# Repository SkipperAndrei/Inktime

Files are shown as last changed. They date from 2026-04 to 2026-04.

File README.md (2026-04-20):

# InkTime Watch

Made by: Giurgiu Andrei-Ștefan 335CA

## Cuprins

1. [Prezentare generală](#1-prezentare-generală)
2. [Diagramă bloc](#2-diagramă-bloc)
3. [BOM – Bill of Materials](#3-bom--bill-of-materials)
4. [Descrierea hardware în detaliu](#4-descrierea-hardware-în-detaliu)
5. [Pinout nRF52840 – atribuire completă](#5-pinout-nrf52840--atribuire-completă)
6. [Estimare consum de energie](#6-estimare-consum-de-energie)
7. [Arhitectura firmware](#7-arhitectura-firmware)
8. [Aplicația mobilă companion](#8-aplicația-mobilă-companion)
9. [Randări produs](#9-randări-produs)

---

## 1. Prezentare generală

**InkTime** este un smartwatch conceput pentru a oferi:

- Afișaj e-paper 1.54" (200×200 px) cu refresh parțial o dată pe minut pentru un cadran digital clar, lizibil la orice lumină.
- Notificări BLE de pe telefon (profil tipic: ≤ 50 notificări/zi) cu alerte haptic.
- Numărare pași permanentă prin accelerometru cu pedometru integrat și trezire prin întrerupere.
- Încărcare USB-C și cale robustă de recuperare/programare prin Tag-Connect TC2030 SWD.

**Principii de proiectare:**

| Principiu | Descriere |
|---|---|
| Power first | Consum mediu minimizat; design interrupt-driven; fără conexiune BLE permanentă |
| Glanceable | UI simplu, contrast ridicat, fără ecrane dense cu text |
| Deterministic | Stări de putere predictibile; cale de recuperare robustă; fără stări hardware nedefinite |
| Buildable | Asamblare SMT repetabilă (JLC) și pași de asamblare manuală expliciți |

---

## 2. Diagramă bloc
Schema bloc

**Legendă interfețe:**

| Interfață | Componente conectate |
|---|---|
| I²C (shared bus) | BQ25180, RT6160, MAX17048, BMA421, DRV2605L |
| SPI | E-paper display controller |
| GPIO | Butoane, PFET e-paper, întreruperi (INT1/INT2 accel, ALRT fuel gauge, /INT charger) |
| USB | nRF52840 native USB (D+/D-) + VBUS detect |
| SWD | Tag-Connect TC2030 (SWDIO, SWDCLK, nRESET) |

---

## 3. BOM – Bill of Materials

| # | Funcție | Componentă | Pachet | LCSC Part | Link JLCPCB | Datasheet |
|---|---|---|---|---|---|---|
| 1 | MCU (BLE + USB) | nRF52840-QIAA-R | aQFN73 7×7 | C190794 | [JLCPCB](https://jlcpcb.com/partdetail/NordicSemiconductor-nRF52840QIAAR/C190794) | [Datasheet](https://infocenter.nordicsemi.com/pdf/nRF52840_PS_v1.7.pdf) |
| 2 | Charger / power-path | BQ25180YBGR | DSBGA-8 | C3682423 | [JLCPCB](https://jlcpcb.com/partdetail/TexasInstruments-BQ25180YBGR/C3682423) | [Datasheet](https://www.ti.com/lit/ds/symlink/bq25180.pdf) |
| 3 | Regulator 3.3V buck-boost | RT6160AWSC | WLCSP-15 | C7065276 | [JLCPCB](https://jlcpcb.com/partdetail/RichtekTech-RT6160AWSC/C7065276) | [Datasheet](https://www.richtek.com/assets/product_file/RT6160A/DS6160A-01.pdf) |
| 4 | Fuel gauge | MAX17048G+T10 | DFN-8 2×2 | C2682616 | [JLCPCB](https://jlcpcb.com/partdetail/MaximIntegrated-MAX17048GT10/C2682616) | [Datasheet](https://www.analog.com/media/en/technical-documentation/data-sheets/MAX17048-MAX17049.pdf) |
| 5 | Accelerometru / pedometru | BMA421 | LGA-12 2×2 | C5242966 | [JLCPCB](https://jlcpcb.com/partdetail/BoschSensortec-BMA421/C5242966) | [Datasheet](https://www.bosch-sensortec.com/media/boschsensortec/downloads/datasheets/bst-bma421-ds000.pdf) |
| 6 | Driver haptic | DRV2605LDGSR | VSSOP-10 | C527464 | [JLCPCB](https://jlcpcb.com/partdetail/TexasInstruments-DRV2605LDGSR/C527464) | [Datasheet](https://www.ti.com/lit/ds/symlink/drv2605l.pdf) |
| 7 | Motor vibrant ERM | LCM1027B3605F | Wire leads | C7528806 | [JLCPCB](https://jlcpcb.com/partdetail/C7528806) | [Datasheet](https://datasheet.lcsc.com/lcsc/2208251630_NOVASEN-LCM1027B3605F_C7528806.pdf) |
| 8 | PFET (power gate EPD) | SI2301CDS | SOT-23 | C10487 | [JLCPCB](https://jlcpcb.com/partdetail/Vishay-SI2301CDS/C10487) | [Datasheet](https://www.vishay.com/docs/63524/si2301cds.pdf) |
| 9 | Conector debug | Tag-Connect TC2030-IDC | PCB footprint | — | [Tag-Connect](https://www.tag-connect.com/product/tc2030-idc-nl) | [Pinout](https://www.tag-connect.com/wp-content/uploads/bsk-pdf-manager/2019/10/TC2030-IDC-NL.pdf) |
| 10 | Afișaj e-paper | 1.54" EPD 200×200 (Good Display GDEW0154M09 sau echivalent) | FPC | — | [Good Display](https://www.good-display.com) | [Datasheet](https://www.good-display.com/companyfile/459.html) |

---

## 4. Descrierea hardware în detaliu

### 4.1 MCU – nRF52840-QIAA

nRF52840 este microcontrolerul central al proiectului. Integrează:

- Procesor ARM Cortex-M4F @ 64 MHz
- Radio BLE 5.0 + IEEE 802.15.4
- USB 2.0 Full Speed nativ (D+/D-)
- 1 MB Flash, 256 KB RAM
- Periferice hardware: multiple SPI, I²C, UART, PWM, ADC, comparatoare

**Alimentare MCU:**

| Rail | Conexiune | Valoare / Notă |
|---|---|---|
| VDD (toți pinii) | VDD 3V3 | 3.3V de la RT6160 |
| VDDH | VDD 3V3 | Mod normal-voltage (nu high-voltage) |
| VSS + pad expus | GND plane | |
| DEC1 | 100nF la GND | |
| DEC4 + DEC6 | 1µF la GND | Nodul DC/DC intern REG1 |
| DECUSB | 4.7µF la GND | Filtrare USB |

**DC/DC intern (REG1):** Firmware-ul activează DCDC1 la runtime. Circuitul extern: DCC → 10µH → 15nH → nod DEC4/DEC6.

**Cristale:**

| Cristal | Pini | Scopul |
|---|---|---|
| 32 MHz | XC1 / XC2 | Sistem principal, radio BLE, USB |
| 32.768 kHz | XL1 / XL2 | RTC, timekeeping, minute tick |

Condensatorii de sarcină ai cristalelor se dimensionează în funcție de CL-ul cristalului ales (ajustare posibilă pe board).

---

### 4.2 Charger – BQ25180YBGR

BQ25180 este un charger linear/power-path pentru LiPo de până la 1A, cu interfață I²C.

**Rol în sistem:**

- Primește 5V de pe USB-C pe pinul IN.
- Oferă VSYS pe pinul SYS — rail intermediar care alimentează regulatorul RT6160.
- Gestionează încărcarea bateriei LiPo pe pinul BAT cu protecție integrată (supraîncărcare, supraîncălzire, scurtcircuit).

**Conexiuni cheie:**

| Pin BQ25180 | Conexiune |
|---|---|
| IN | VBUS 5V (USB) |
| BAT | VBAT (LiPo +) |
| SYS | VSYS → RT6160 VIN |
| SCL / SDA | I²C shared bus |
| /INT | GPIO MCU (întrerupere opțională pentru evenimente charger) |
| TS / MR | Strapped cu 10kΩ la GND (Rev A) |

**Decuplare:** CIN = 1µF, CSYS = 10µF, CBAT = 1µF (minim, dimensionate cu derating termic).

**Adresă I²C:** `0x6A`

---

### 4.3 Regulator 3.3V – RT6160AWSC

RT6160 este un convertor buck-boost care menține 3.3V fix pe toată plaja de descărcare a LiPo (de la ~4.2V până la ~3.0V și sub). Asigură că VBAT scăzut nu provoacă brownout pe MCU sau periferice.

**Conexiuni cheie:**

| Pin RT6160 | Conexiune |
|---|---|
| VIN | VSYS (ieșirea SYS a BQ25180) |
| VOUT | VDD 3V3 |
| VSEL | GND (selectează fix 3.3V) |
| EN | VSYS (always-on când VSYS e prezent) |
| SCL / SDA | I²C shared bus (opțional, pentru telemetrie / DVFS viitor) |

**Componentă externă putere:** Inductor 0.47µH, input multi-22µF, output 10µF (valori recomandate Richtek).

**Adresă I²C:** `0x75`

---

### 4.4 Fuel Gauge – MAX17048G+T10

MAX17048 măsoară tensiunea bateriei LiPo prin algoritmul ModelGauge și raportează SOC (State of Charge) în procente prin I²C.

**Conexiuni cheie:**

| Pin MAX17048 | Conexiune |
|---|---|
| BAT / VDD | VBAT |
| SDA / SCL | I²C shared bus |
| ALRT | GPIO MCU (active low, pull-up la VDD 3V3) → sursă de trezire din sleep |

**Decuplare:** 0.1µF lângă VDD.

**Adresă I²C:** `0x36`

**Funcționalitate:** Pinul ALRT generează o întrerupere când SOC scade sub pragul configurat (ex. 5%) — MCU se trezește, afișează avertisment baterie slabă și/sau inițiază BLE disconnect.

---

### 4.5 Accelerometru / Pedometru – BMA421

BMA421 este un accelerometru triaxial de înaltă performanță cu pedometru hardware integrat, optimizat pentru purtabila (consum < 200µA în mod step counter).

**Mod de operare principal:** I²C (CSB strapped high, SDO strapped low → adresă 0x18).

**Conexiuni cheie:**

| Pin BMA421 | Conexiune |
|---|---|
| VDD / VDDIO | VDD 3V3 (decuplare 0.1µF per pin) |
| SDA / SCL | I²C shared bus |
| CSB | High → mod I²C |
| SDO | Low → adresă 0x18 |
| INT1 | P0.08 → trezire primară din Deep Sleep (pas detectat, motion) |
| INT2 | P1.08 → evenimente secundare / debug |

**Funcționalitate:** Pedometrul hardware numără pași fără implicarea MCU-ului. MCU se trezește doar la întreruperea INT1 pentru a citi și cumula datele, reducând consumul la minimum.

---

### 4.6 Driver haptic – DRV2605L + Motor ERM LCM1027B3605F

DRV2605L controlează motorul vibrant ERM (Eccentric Rotating Mass) prin forme de undă preprogramate stocate în ROM intern (biblioteca Immersion HD), selectate prin I²C.

**Conexiuni cheie:**

| Pin DRV2605L | Conexiune |
|---|---|
| VDD | VDD 3V3 (decuplare locală) |
| SDA / SCL | I²C shared bus |
| EN | P0.12 → shutdown complet între evenimente haptic |
| OUT+ / OUT- | Terminalele motorului ERM |

**Adresă I²C:** `0x5A`

**Politică de consum:** EN pus LOW între evenimente haptic elimină curentul de quiescent al driverului. Motorul rulează doar pe durata unui pattern (tipic 50–300ms).

---

### 4.7 Afișaj E-paper 1.54" (200×200)

Afișajul e-paper păstrează imaginea fără consum de energie în stare statică — ideal pentru un cadran de ceas. Consumă curent doar în timpul refresh-ului.

**Interfață:** SPI + 3 GPIO de control.

**Conexiuni cheie:**

| Semnal | Pin MCU | Rol |
|---|---|---|
| SCK | P0.02 | Clock SPI |
| MOSI | P0.03 | Date SPI (write-only) |
| CS | P0.05 | Chip select |
| DC | P0.15 | Data / Command select |
| RST | P0.16 | Reset panel |
| BUSY | P0.17 | Semnal panel ocupat (polling) |
| PFET gate | P1.01 | Power gate VEPD (prin rezistor 100Ω; pull-up 100kΩ gate-source) |

**Power gating VEPD:** Un P-FET (SI2301CDS) comutează alimentarea afișajului (VEPD) din VDD 3V3. Firmware-ul poate dezactiva VEPD complet între refresh-uri pentru a elimina curentul de leakage al display-ului și al FPC.

**Politică refresh:**

- Refresh parțial la fiecare minut (time update) — consum minim, fără ghosting vizibil pe termen scurt.
- Refresh complet la intervale configurabile (ex. la fiecare oră sau la cerere) pentru eliminarea ghosting-ului acumulat.

**Rezistori de serie opționali (DNP):** 100Ω–1kΩ pe liniile SPI/control pentru a reduce riscul de back-power când VEPD este dezactivat.

---

### 4.8 Butoane

Trei butoane mecanice active-low:

| Buton | Pin MCU | Conexiune |
|---|---|---|
| UP | P0.13 | GPIO → Switch → GND |
| DOWN | P0.14 | GPIO → Switch → GND |
| ENTER / ESC | P1.00 | GPIO → Switch → GND |

Firmware-ul activează pull-up intern pe fiecare pin și configurează wake-on-low + debounce software (tipic 20–50ms).

---

### 4.9 Interfața de programare – Tag-Connect TC2030 SWD

| Pin TC2030 | Semnal |
|---|---|
| 1 | VTref (VDD 3V3) — referință tensiune pentru debugger |
| 2 | SWDIO |
| 3 | GND |
| 4 | SWDCLK |
| 5 | GND |
| 6 | nRESET |

Board-ul este self-powered (baterie sau USB); TC2030 nu trebuie să furnizeze curent. VTref este obligatoriu pentru ca debugger-ul să detecteze tensiunea I/O a target-ului.

---

## 5. Pinout nRF52840 – atribuire completă

| Pin nRF52840 | Funcție | Componentă / Semnal | Justificare alegere |
|---|---|---|---|
| P0.02 | SPI SCK | E-paper clock | SPI0 hardware; alocare convenabilă pentru routing PCB |
| P0.03 | SPI MOSI | E-paper date | SPI0 hardware |
| P0.05 | SPI CS | E-paper chip select | GPIO flexibil, contiguitate cu celelalte pini SPI |
| P0.06 | I²C SDA | Bus I²C shared | I2C0 hardware Nordic; pull-up extern 10kΩ |
| P0.07 | I²C SCL | Bus I²C shared | I2C0 hardware Nordic; pull-up extern 10kΩ |
| P0.08 | GPIO INPUT | BMA421 INT1 | Capacitate sense GPIO → wake din Deep Sleep; pin cu DETECT |
| P0.12 | GPIO OUTPUT | DRV2605L EN | Control shutdown haptic; GPIO simplu sufficient |
| P0.13 | GPIO INPUT | Buton UP | Sense GPIO, wake-on-low, pull-up intern |
| P0.14 | GPIO INPUT | Buton DOWN | Sense GPIO, wake-on-low, pull-up intern |
| P0.15 | GPIO OUTPUT | EPD DC | Control Data/Command display; GPIO rapid |
| P0.16 | GPIO OUTPUT | EPD RST | Reset panel; GPIO simplu |
| P0.17 | GPIO INPUT | EPD BUSY | Polling stare panel; GPIO simplu |
| P1.00 | GPIO INPUT | Buton ENTER/ESC | Sense GPIO, wake-on-low, pull-up intern |
| P1.01 | GPIO OUTPUT | PFET gate VEPD | Control alimentare afișaj; pull-up extern gate-source (default OFF) |
| P1.08 | GPIO INPUT | BMA421 INT2 | Eveniment secundar accelerometru / debug |
| USBDP / USBDM | USB D+ / D- | USB-C conector | Pereche diferențială native USB nRF52840; ESD lângă conector |
| VBUS | USB VBUS detect | USB 5V | Detecție attach/detach USB |
| SWDIO / SWDCLK | SWD | TC2030 pin 2 / 4 | Programare și debug hardware |
| nRESET | Reset | TC2030 pin 6 | Resetare externă prin debugger |
| XC1 / XC2 | Crystal 32 MHz | Cristal extern | Ceas sistem, radio BLE, USB |
| XL1 / XL2 | Crystal 32.768 kHz | Cristal RTC extern | RTC, minute tick, sleep scheduling |
| DEC1 | Decuplare | 100nF → GND | Rail intern nRF |
| DEC4 / DEC6 | Decuplare DC/DC | 1µF → GND | Nod inductor DC/DC REG1 |
| DECUSB | Decuplare USB | 4.7µF → GND | Filtrare rail USB intern |

**Bus I²C – hartă adrese (7-bit):**

| Adresă | Dispozitiv |
|---|---|
| 0x18 | BMA421 (accelerometru) |
| 0x36 | MAX17048 (fuel gauge) |
| 0x5A | DRV2605L (haptic driver) |
| 0x6A | BQ25180 (charger) |
| 0x75 | RT6160 (regulator) |

---

## 6. Estimare consum de energie

### 6.1 Profilul tipic de utilizare

| Eveniment | Frecvență | Energie estimată |
|---|---|---|
| Refresh parțial e-paper | 1×/minut | ~5–15 mJ/refresh |
| Notificare BLE + haptic + display | 50×/zi | ~10–20 mJ/eveniment |
| Step counter (BMA421) | continuu (MCU dormit) | ~5–10 µA curent static BMA421 |
| Deep Sleep MCU | majoritar | ~3–5 µA (MCU) + RTC |

### 6.2 Buget curent mediu (estimat)

| Componentă | Curent mediu estimat |
|---|---|
| nRF52840 Deep Sleep + RTC | ~3 µA |
| BMA421 step counter mode | ~5 µA |
| MAX17048 activ | ~23 µA |
| E-paper (static, VEPD off) | ~0 µA |
| E-paper refresh (parțial, 1/min, pulsed) | ~150–300 µA mediat pe minut |
| **Total estimat mediu** | **~180–340 µA** |

---

## 7. Arhitectura firmware

### 7.1 Stack

- **RTOS:** Zephyr OS (recomandat pentru maturitate BLE stack) sau event loop lightweight.
- **Limbaj:** C / C++ (Zephyr NCS).

### 7.2 Module principale

| Modul | Responsabilități |
|---|---|
| HAL | GPIO, I²C, SPI, timere, întreruperi, watchdog |
| Power Manager | Stări sleep, surse wake, duty cycles, power gating display |
| Timekeeping | RTC, timezone, sincronizare timp, planificare minute tick |
| Display Driver | Init, refresh parțial/complet, frame buffer, polling BUSY |
| BLE Manager | Advertising, conexiune, servicii GATT, notificări, bonding |
| Notification Service | Coadă mesaje, deduplicare, politică render, trigger haptic |
| Activity Service | Init BMA421, citire pași, reset zilnic |
| Battery Service | Citiri MAX17048, alerte baterie slabă, stare charger BQ25180 |
| Haptics Service | Init DRV2605L, pattern-uri, politică enable/disable |
| Storage | NVM pentru setări, istoric pași, preferințe notificări |
| Diagnostics | Log-uri debug, info build, hook-uri self-test |

### 7.3 Stări de putere și surse de trezire

```
┌─────────────┐   RTC tick / Button / INT / BLE event  ┌──────────────┐
│  Deep Sleep  │──────────────────────────────────────►│   Active      │
│ (radio off)  │◄──────────────────────────────────────│ (render/BLE)  │
└─────────────┘           Task complet                 └──────────────┘
        ▲                                                      │
        │                   Idle/Standby                       │
        └──────────────────────────────────────────────────────┘
```

**Surse de trezire din Deep Sleep:**

- RTC minute tick
- Butoane (GPIO sense)
- BMA421 INT1/INT2 (pași/mișcare)
- MAX17048 ALRT (prag baterie slabă)
- BQ25180 /INT (eveniment charger)
- BLE events (ferestre programate)

### 7.4 Servicii BLE GATT (MVP)

| Serviciu | UUID | Descriere |
|---|---|---|
| Device Information (DIS) | Standard | Model, versiune firmware |
| Battery Service (BAS) | Standard | Procent baterie (MAX17048) |
| Custom Notification Service | Custom | Push notificări, clear, ack |
| Time Sync | Custom | Setare oră/timezone; proxy NTP opțional |
| DFU Service | Custom (opțional) | Update firmware OTA |

**Payload notificare:** timestamp, app id, titlu, corp (trunchiat), prioritate, vibration pattern id — optimizat pentru BLE MTU cu suport chunking.

---

## 8. Aplicația mobilă companion

### 8.1 Strategie platformă

- MVP: o platformă prima (Android sau iOS), cu plan clar de paritate.
- Cross-platform: Flutter sau React Native dacă cerințele BLE stack sunt satisfăcute.
- Native: Kotlin (Android) / Swift (iOS) pentru fiabilitate BLE maximă.

### 8.2 Module app

| Modul | Responsabilități |
|---|---|
| BLE Transport | Scan, connect, bonding, MTU, reconectare, comportament background |
| Device Model | Stare cached: baterie, firmware, setări, last seen |
| Notification Bridge | Capturare notificări OS, filtrare, formatare, coadă send |
| Settings UI | Allowlist/blocklist, ore liniștite, pattern-uri vibrație |
| Time Service | Sincronizare oră + timezone, politică drift |
| DFU/Update | Download/verify firmware, transfer, progres, rollback |

### 8.3 Pipeline notificări

```
Eveniment OS → Filtrare reguli (app list, quiet hours) → Render payload compact →
→ Coadă cu retry/backoff (dacă watch deconectat) → Send BLE → Ack opțional
```

---

### 9 Randări produs

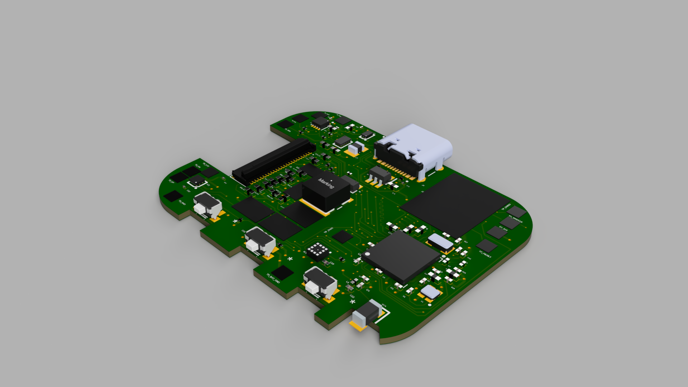
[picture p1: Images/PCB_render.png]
RandarePCB


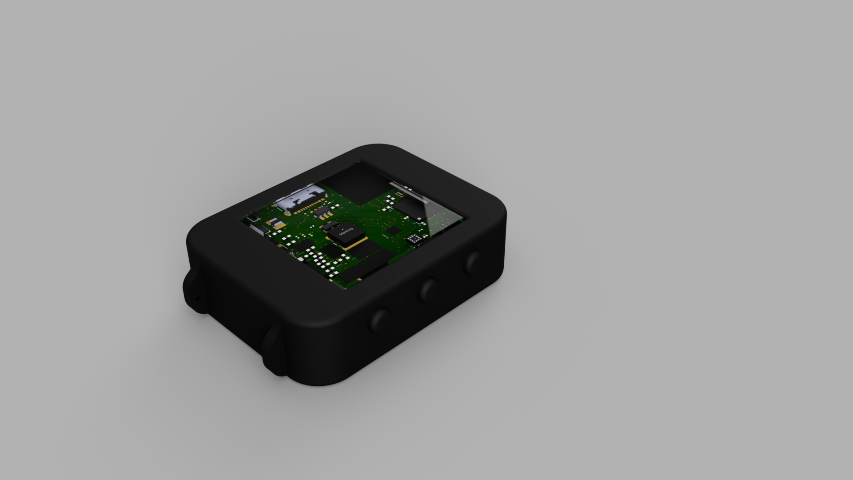
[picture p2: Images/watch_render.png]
RandareCeas


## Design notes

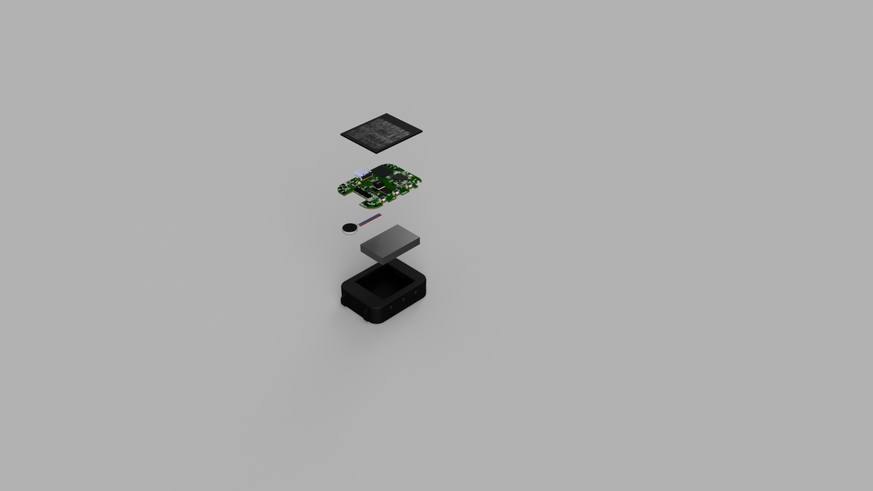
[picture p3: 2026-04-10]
Images/exploded_render.png

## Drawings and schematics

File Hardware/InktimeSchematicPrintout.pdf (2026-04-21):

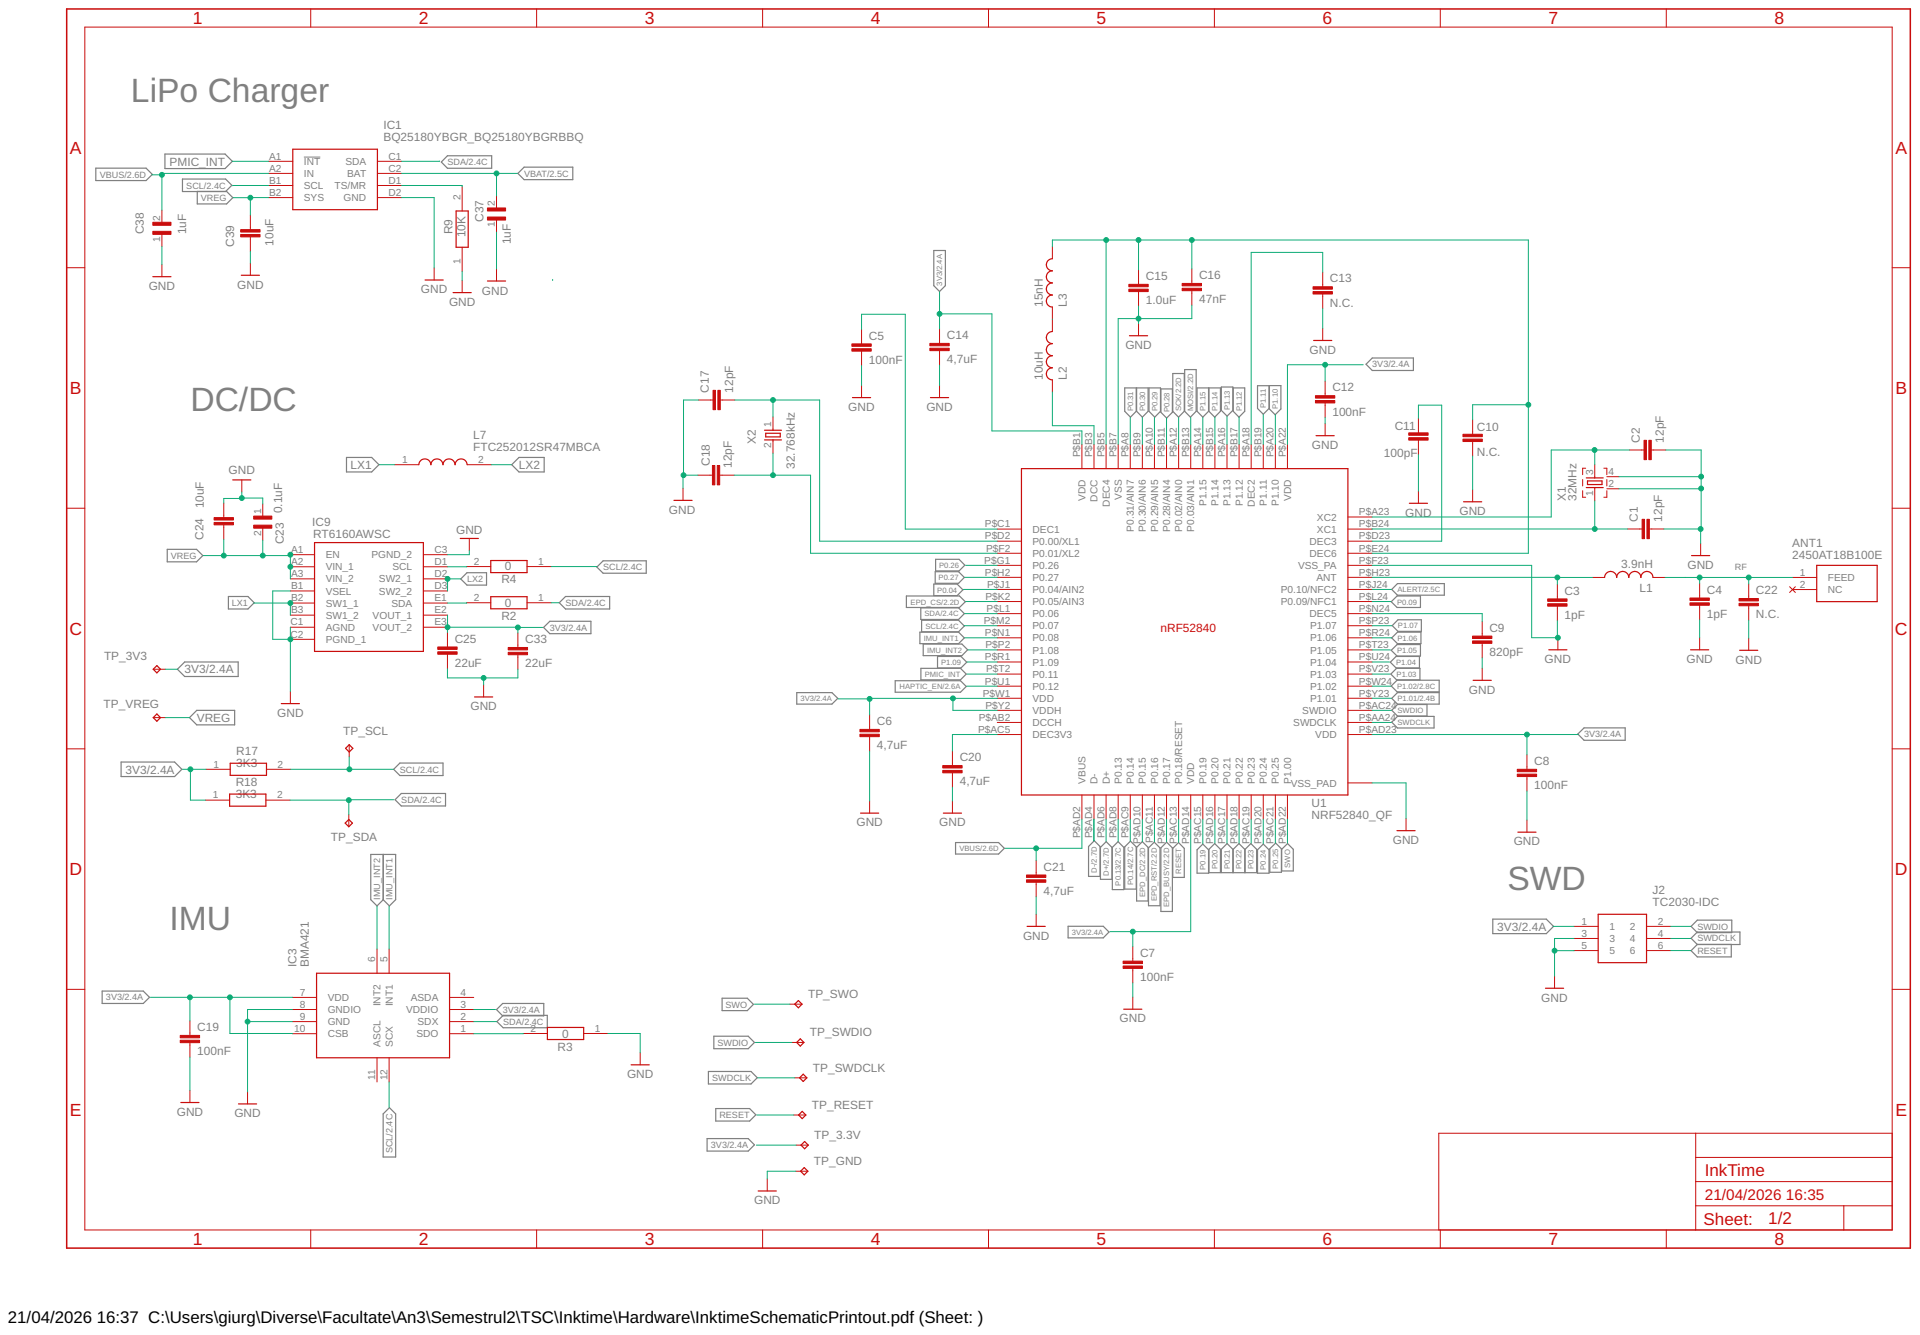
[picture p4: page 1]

21/04/2026 16:37 C:\Users\giurg\Diverse\Facultate\An3\Semestrul2\TSC\Inktime\Hardware\InktimeSchematicPrintout.pdf (Sheet: )

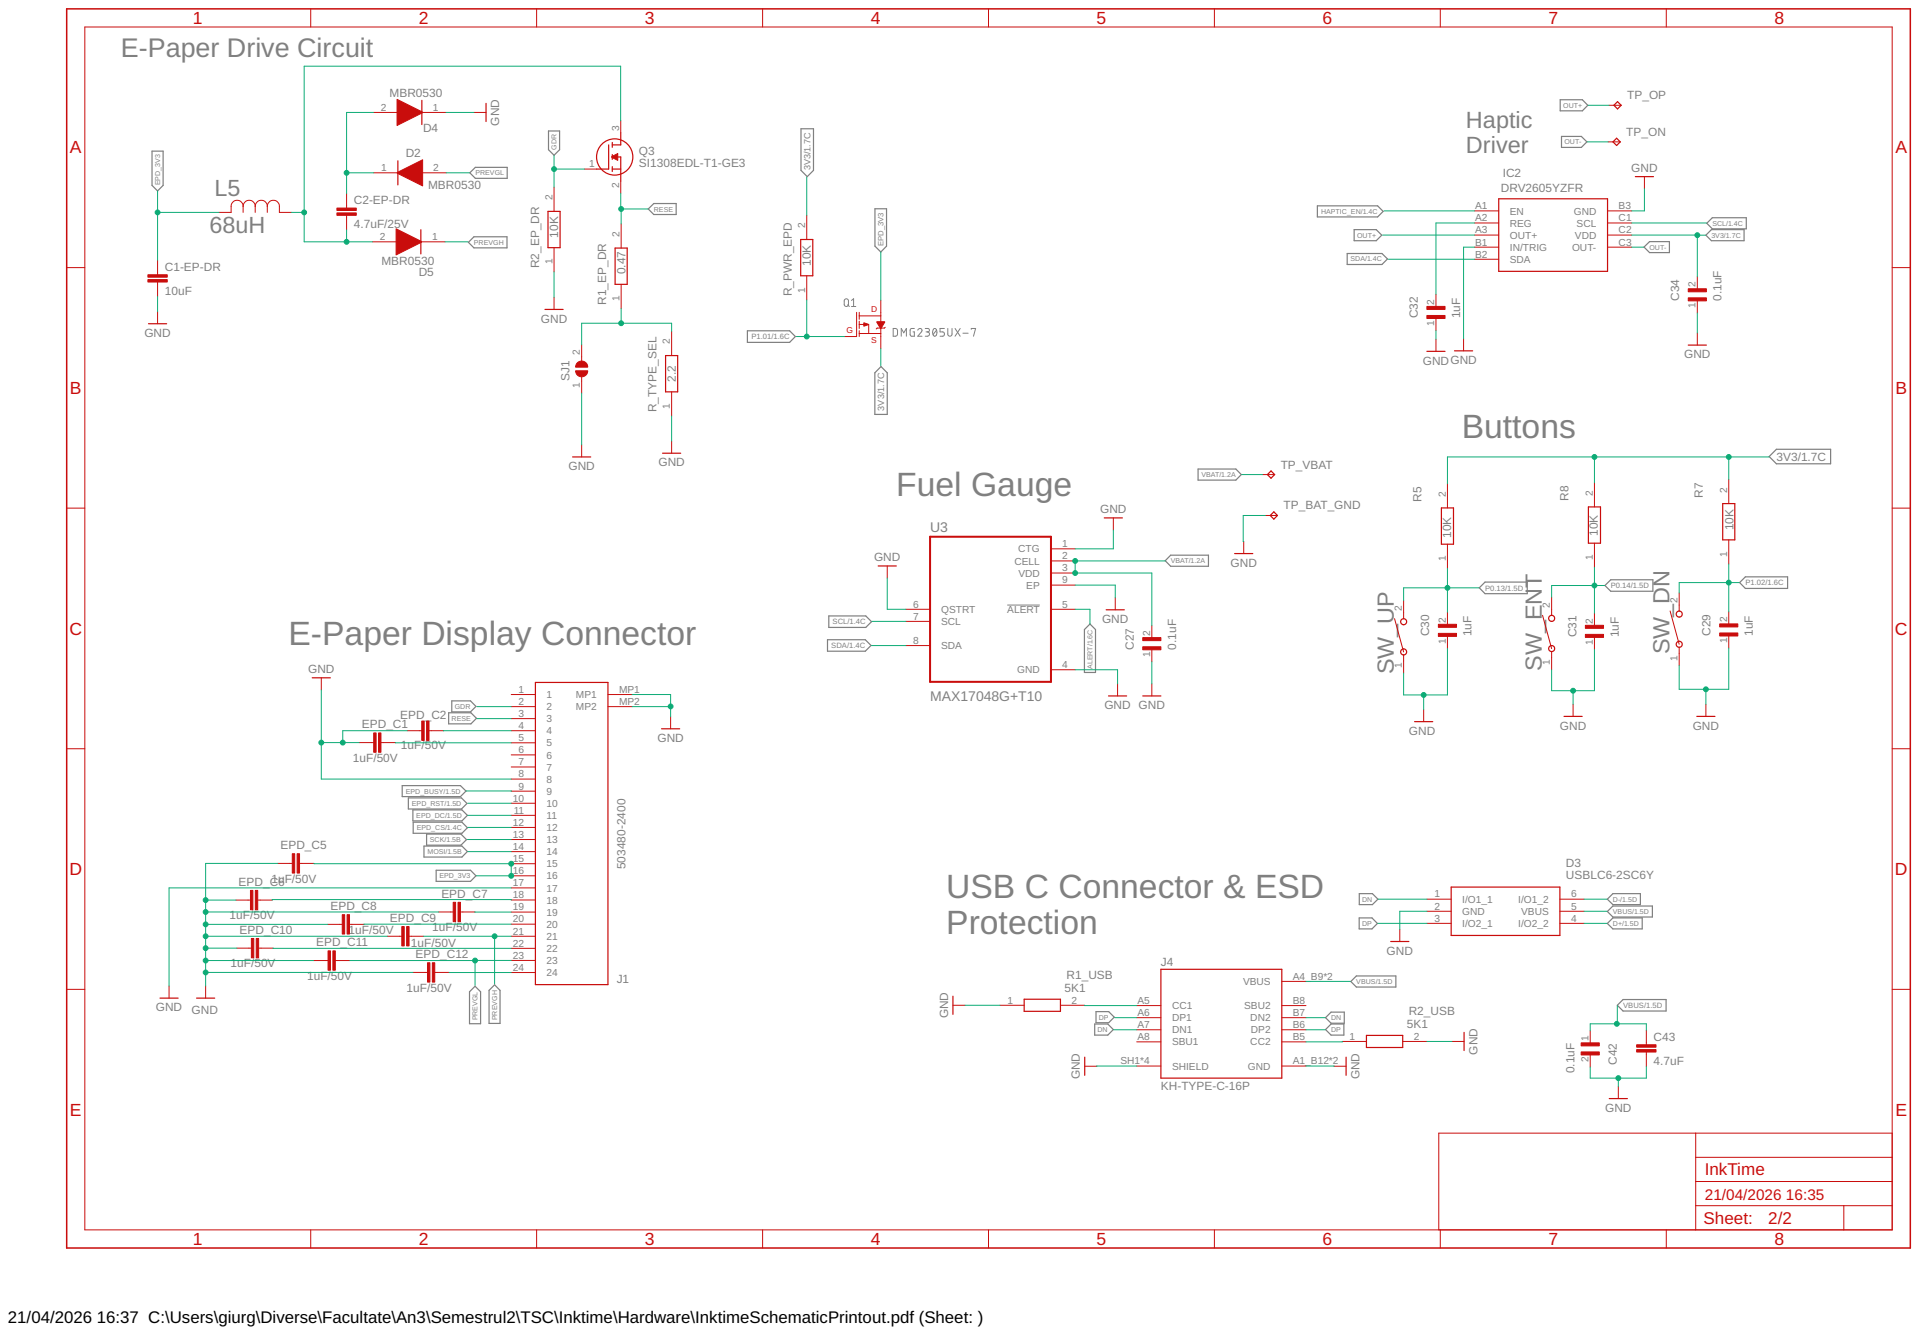
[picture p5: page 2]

EPD_C8 | 19

1uF/50V | EPD_C9 | 20
EPD_C10 | 1uF/50V | 1uF/50V 21

EPD_C11 | 1uF/50V | 22

EPD_C12 | 23

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

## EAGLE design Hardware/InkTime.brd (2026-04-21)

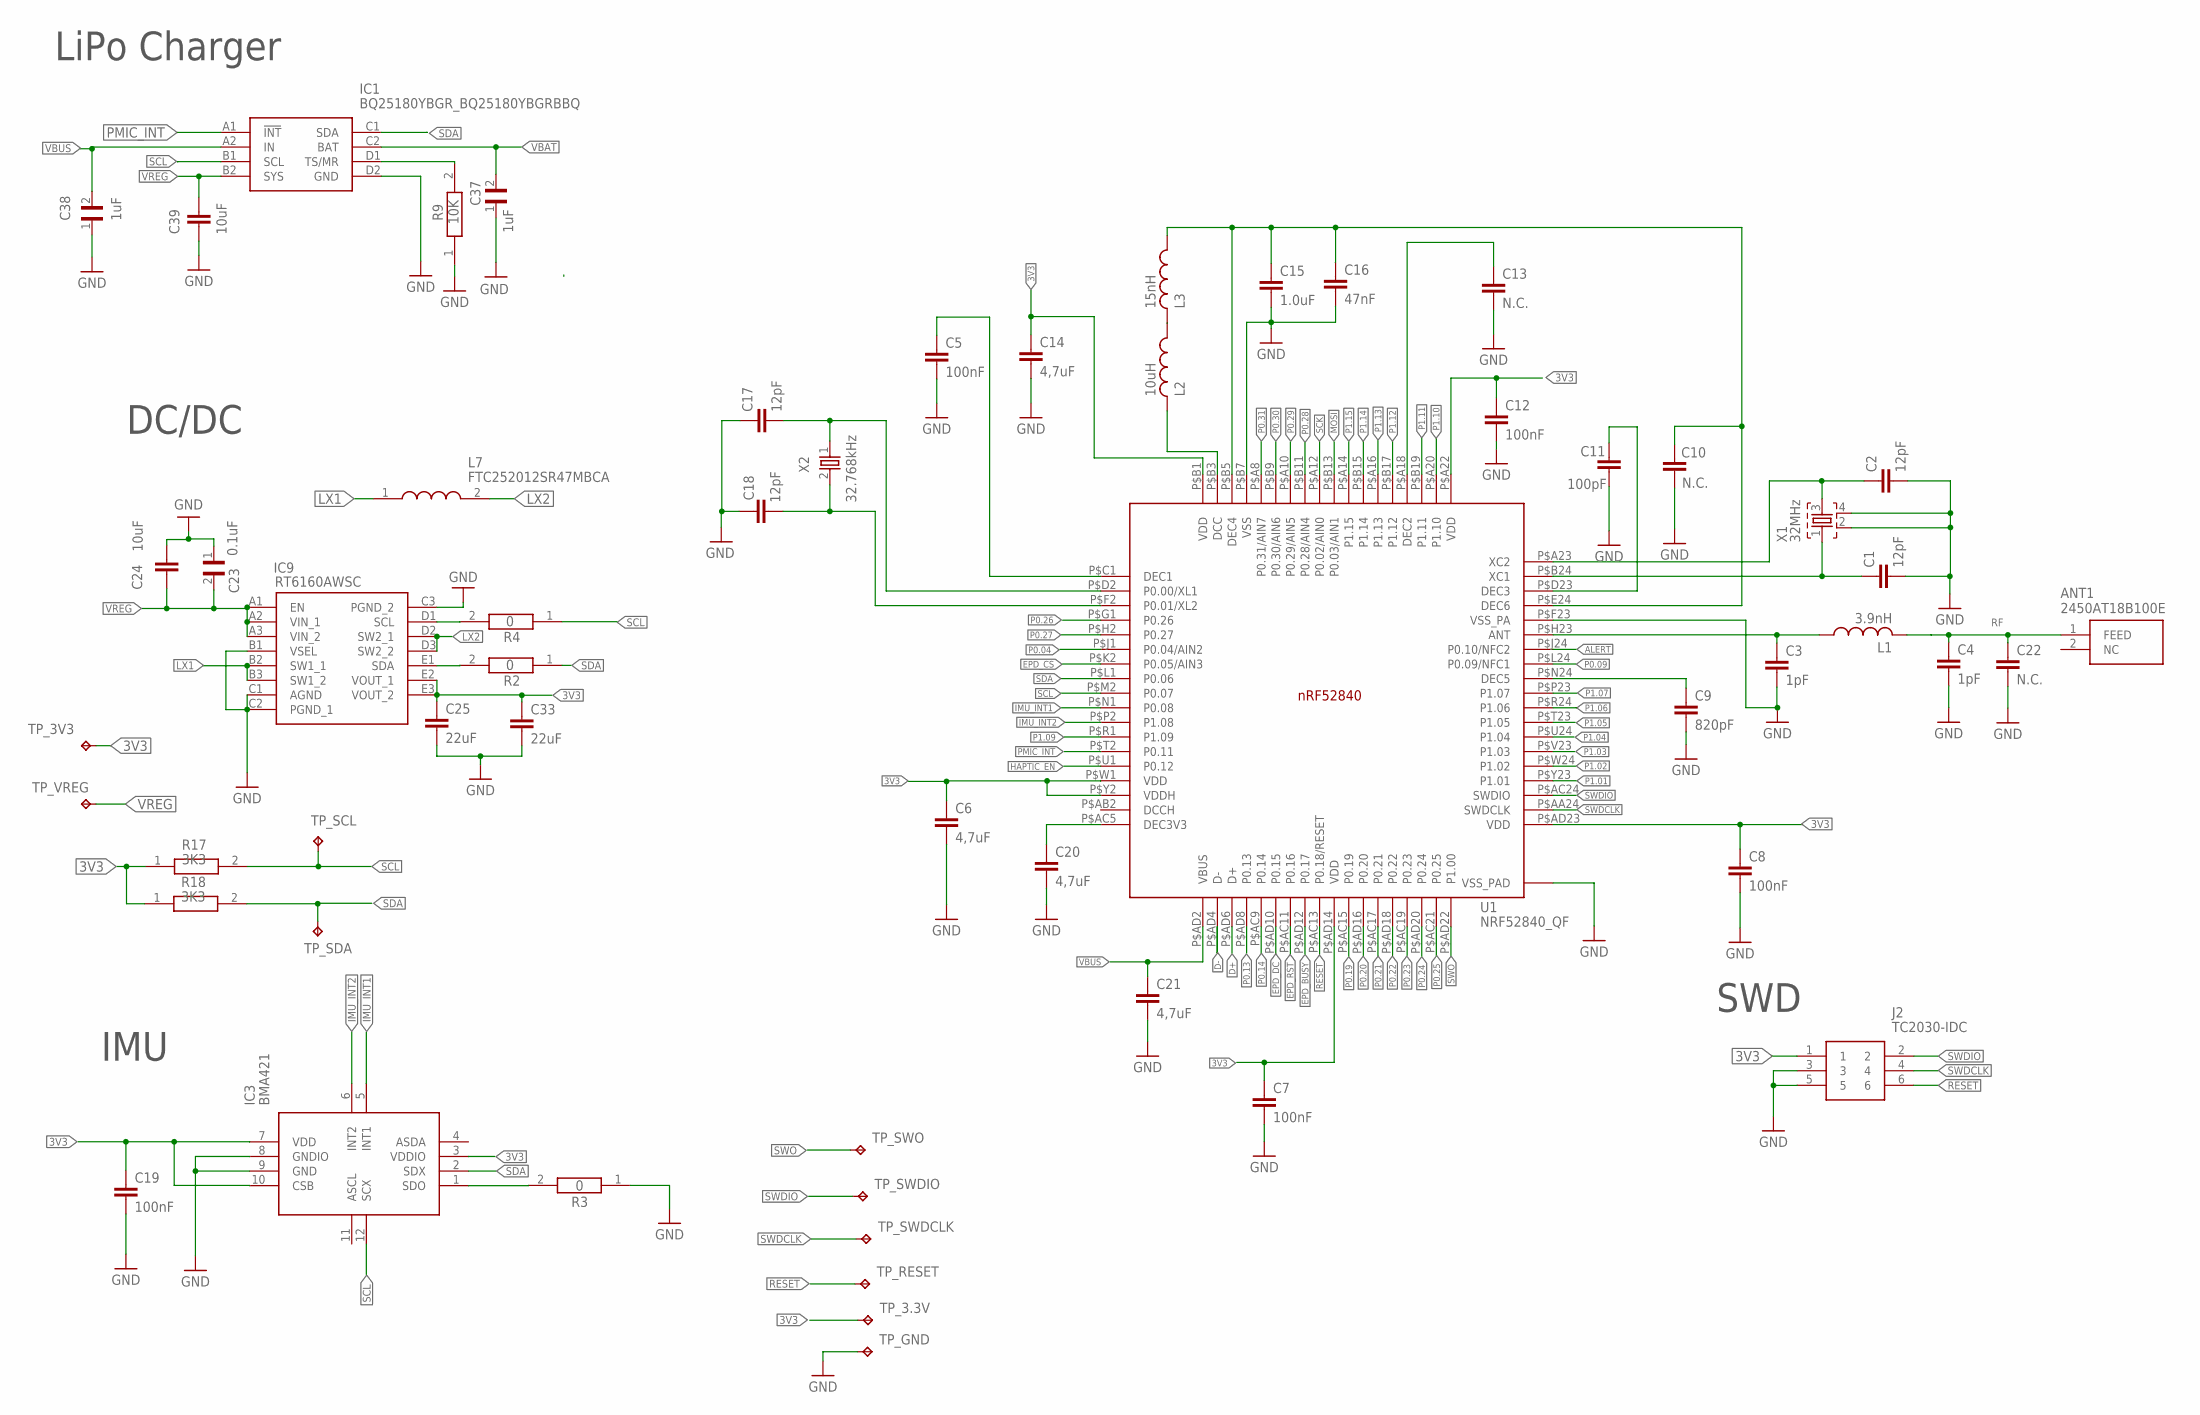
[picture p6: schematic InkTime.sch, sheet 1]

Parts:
ANT1: 2450AT18B100E; 2450AT18B100E_ANTC3216X140N
C1, C2, C17, C18: 12pF; NORDIC_NRF_3_RESC0201_N
C3, C4: 1pF; NORDIC_NRF_3_RESC0201_N
C5, C7, C8, C12, C19: 100nF; NORDIC_NRF_3_RESC0201_N
C6, C14, C20, C21: 4,7uF; NORDIC_NRF_3_RESC0402_N
C9: 820pF; NORDIC_NRF_3_RESC0201_N
C10, C13, C22: N.C.; NORDIC_NRF_3_RESC0201_N
C11: 100pF; NORDIC_NRF_3_RESC0201_N
C15: 1.0uF; NORDIC_NRF_3_RESC0402_N
C16: 47nF; NORDIC_NRF_3_RESC0201_N
C23: 0.1uF; GRM011R60J152KE01L_2_CAPC0201X13N
C24, C39: 10uF; NORDIC_NRF_3_RESC0402_N
C25, C33: 22uF; NORDIC_NRF_3_RESC0402_N
C37, C38: 1uF; GRM011R60J152KE01L_2_CAPC0201X13N
IC1: BQ25180YBGR_BQ25180YBGRBBQ; BQ25180YBGR_BGA8C40P2X4_100X155X50
IC3: BMA421; BMA423_BMA423
IC9: RT6160AWSC; RT6160AWSC_BGA15C40P3X5_140X230X60
J2: TC2030-IDC; TC2030-IDC_TC2030IDC
L1: 3.9nH; NORDIC_NRF_2_RESC0201_N
L2: 10uH; NORDIC_NRF_2_RESC0201_N
L3: 15nH; NORDIC_NRF_2_RESC0201_N
L7: FTC252012SR47MBCA; MLP2016SR47MT0S1_INDC2016X100N
R2, R3, R4: 0; CPF0201D7K68C1_0201
R9: 10K; CPF0201D7K68C1_0201
R17, R18: 3K3; CPF0201D7K68C1_0201
TP_3.3V, TP_3V3: HECTOR_WATCH_1_TPTP20R; HECTOR_WATCH_1_TP20R
TP_GND: HECTOR_WATCH_1_TPTP20R; HECTOR_WATCH_1_TP20R
TP_RESET: HECTOR_WATCH_1_TPTP20R; HECTOR_WATCH_1_TP20R
TP_SCL: HECTOR_WATCH_1_TPTP20R; HECTOR_WATCH_1_TP20R
TP_SDA: HECTOR_WATCH_1_TPTP20R; HECTOR_WATCH_1_TP20R
TP_SWDCLK: HECTOR_WATCH_1_TPTP20R; HECTOR_WATCH_1_TP20R
TP_SWDIO: HECTOR_WATCH_1_TPTP20R; HECTOR_WATCH_1_TP20R
TP_SWO: HECTOR_WATCH_1_TPTP20R; HECTOR_WATCH_1_TP20R
TP_VREG: HECTOR_WATCH_1_TPTP20R; HECTOR_WATCH_1_TP20R
U1: NRF52840_QF; NORDIC_NRF_4_AQFN50P700X700X85_HS-74N
X1: 32MHz; NORDIC_NRF_BT-XTAL_2016_N
X2: 32.768kHz; NORDIC_NRF_1_XTAL_3215_N

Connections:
3V3: C6.1, C7.1, C8.1, C12.1, C14.1, C19.1, C25.1, C33.1, IC3.3 (VDDIO), IC3.7 (VDD), IC3.10 (CSB), IC9.E2 (VOUT_1), IC9.E3 (VOUT_2), J2.1, R17.1, R18.1, TP_3.3V.TP, TP_3V3.TP, U1.P$A22 (VDD), U1.P$AD14 (VDD), U1.P$AD23 (VDD), U1.P$B1 (VDD), U1.P$W1 (VDD), U1.P$Y2 (VDDH); also elsewhere on the board
ALERT: U1.P$J24 (P0.10/NFC2); also elsewhere on the board
D+: U1.P$AD6 (D+); also elsewhere on the board
D-: U1.P$AD4 (D-); also elsewhere on the board
EPD_BUSY: U1.P$AD12 (P0.17); also elsewhere on the board
EPD_CS: U1.P$K2 (P0.05/AIN3); also elsewhere on the board
EPD_DC: U1.P$AD10 (P0.15); also elsewhere on the board
EPD_RST: U1.P$AC11 (P0.16); also elsewhere on the board
GND: C1.2, C2.2, C3.2, C4.2, C5.2, C6.2, C7.2, C8.2, C9.2, C10.2, C11.2, C12.2, C13.2, C14.2, C15.2, C16.2, C17.1, C18.2, C19.2, C20.2, C21.2, C22.2, C23.1, C24.1, C25.2, C33.2, C37.1, C38.1, C39.2, IC1.D2 (GND), IC3.8 (GNDIO), IC3.9 (GND), IC9.B1 (VSEL), IC9.C1 (AGND), IC9.C2 (PGND_1), IC9.C3 (PGND_2), J2.3, J2.5, R3.1, R9.1, TP_GND.TP, U1.P$74 (VSS_PAD), U1.P$75 (VSS_PAD), U1.P$76 (VSS_PAD), U1.P$77 (VSS_PAD), U1.P$78 (VSS_PAD), U1.P$79 (VSS_PAD), U1.P$80 (VSS_PAD), U1.P$81 (VSS_PAD), U1.P$82 (VSS_PAD), U1.P$83 (VSS_PAD), U1.P$84 (VSS_PAD), U1.P$85 (VSS_PAD), U1.P$86 (VSS_PAD), U1.P$87 (VSS_PAD), U1.P$88 (VSS_PAD), U1.P$89 (VSS_PAD), U1.P$90 (VSS_PAD), U1.P$B7 (VSS), U1.P$F23 (VSS_PA), X1.2, X1.4; also elsewhere on the board
HAPTIC_EN: U1.P$U1 (P0.12); also elsewhere on the board
IMU_INT1: IC3.5 (INT1), U1.P$N1 (P0.08)
IMU_INT2: IC3.6 (INT2), U1.P$P2 (P1.08)
LX1: IC9.B2 (SW1_1), IC9.B3 (SW1_2), L7.1
LX2: IC9.D2 (SW2_1), IC9.D3 (SW2_2), L7.2
MOSI: U1.P$B13 (P0.03/AIN1); also elsewhere on the board
unnamed: IC1.D1 (TS/MR), R9.2
unnamed: IC9.D1 (SCL), R4.2
unnamed: IC9.E1 (SDA), R2.2
unnamed: IC3.1 (SDO), R3.2
unnamed: C9.1, U1.P$N24 (DEC5)
unnamed: C3.1, L1.1, U1.P$H23 (ANT)
unnamed: C11.1, U1.P$D23 (DEC3)
unnamed: C10.1, C15.1, C16.1, L3.1, U1.P$B5 (DEC4), U1.P$E24 (DEC6)
unnamed: C2.1, U1.P$A23 (XC2), X1.3
unnamed: C1.1, U1.P$B24 (XC1), X1.1
unnamed: C13.1, U1.P$A18 (DEC2)
unnamed: L2.1, L3.2
unnamed: L2.2, U1.P$B3 (DCC)
unnamed: C5.1, U1.P$C1 (DEC1)
unnamed: C17.2, U1.P$D2 (P0.00/XL1), X2.1
unnamed: C18.1, U1.P$F2 (P0.01/XL2), X2.2
unnamed: C20.1, U1.P$AC5 (DEC3V3)
P0.04: U1.P$J1 (P0.04/AIN2)
P0.09: U1.P$L24 (P0.09/NFC1)
P0.13: U1.P$AD8 (P0.13); also elsewhere on the board
P0.14: U1.P$AC9 (P0.14); also elsewhere on the board
P0.19: U1.P$AC15 (P0.19)
P0.20: U1.P$AD16 (P0.20)
P0.21: U1.P$AC17 (P0.21)
P0.22: U1.P$AD18 (P0.22)
P0.23: U1.P$AC19 (P0.23)
P0.24: U1.P$AD20 (P0.24)
P0.25: U1.P$AC21 (P0.25)
P0.26: U1.P$G1 (P0.26)
P0.27: U1.P$H2 (P0.27)
P0.28: U1.P$B11 (P0.28/AIN4)
P0.29: U1.P$A10 (P0.29/AIN5)
P0.30: U1.P$B9 (P0.30/AIN6)
P0.31: U1.P$A8 (P0.31/AIN7)
P1.01: U1.P$Y23 (P1.01); also elsewhere on the board
P1.02: U1.P$W24 (P1.02); also elsewhere on the board
P1.03: U1.P$V23 (P1.03)
P1.04: U1.P$U24 (P1.04)
P1.05: U1.P$T23 (P1.05)
P1.06: U1.P$R24 (P1.06)
P1.07: U1.P$P23 (P1.07)
P1.09: U1.P$R1 (P1.09)
P1.10: U1.P$A20 (P1.10)
P1.11: U1.P$B19 (P1.11)
P1.12: U1.P$B17 (P1.12)
P1.13: U1.P$A16 (P1.13)
P1.14: U1.P$B15 (P1.14)
P1.15: U1.P$A14 (P1.15)
PMIC_INT: IC1.A1 (!INT), U1.P$T2 (P0.11)
RESET: J2.6, TP_RESET.TP, U1.P$AC13 (P0.18/RESET)
RF: ANT1.1 (FEED), C4.1, C22.1, L1.2
SCK: U1.P$A12 (P0.02/AIN0); also elsewhere on the board
SCL: IC1.B1 (SCL), IC3.12 (SCX), R4.1, R17.2, TP_SCL.TP, U1.P$M2 (P0.07); also elsewhere on the board
SDA: IC1.C1 (SDA), IC3.2 (SDX), R2.1, R18.2, TP_SDA.TP, U1.P$L1 (P0.06); also elsewhere on the board
SWDCLK: J2.4, TP_SWDCLK.TP, U1.P$AA24 (SWDCLK)
SWDIO: J2.2, TP_SWDIO.TP, U1.P$AC24 (SWDIO)
SWO: TP_SWO.TP, U1.P$AD22 (P1.00)
VBAT: C37.2, IC1.C2 (BAT); also elsewhere on the board
VBUS: C21.1, C38.2, IC1.A2 (IN), U1.P$AD2 (VBUS); also elsewhere on the board
VREG: C23.2, C24.2, C39.1, IC1.B2 (SYS), IC9.A1 (EN), IC9.A2 (VIN_1), IC9.A3 (VIN_2), TP_VREG.TP

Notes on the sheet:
LiPo Charger
DC/DC
IMU
SWD

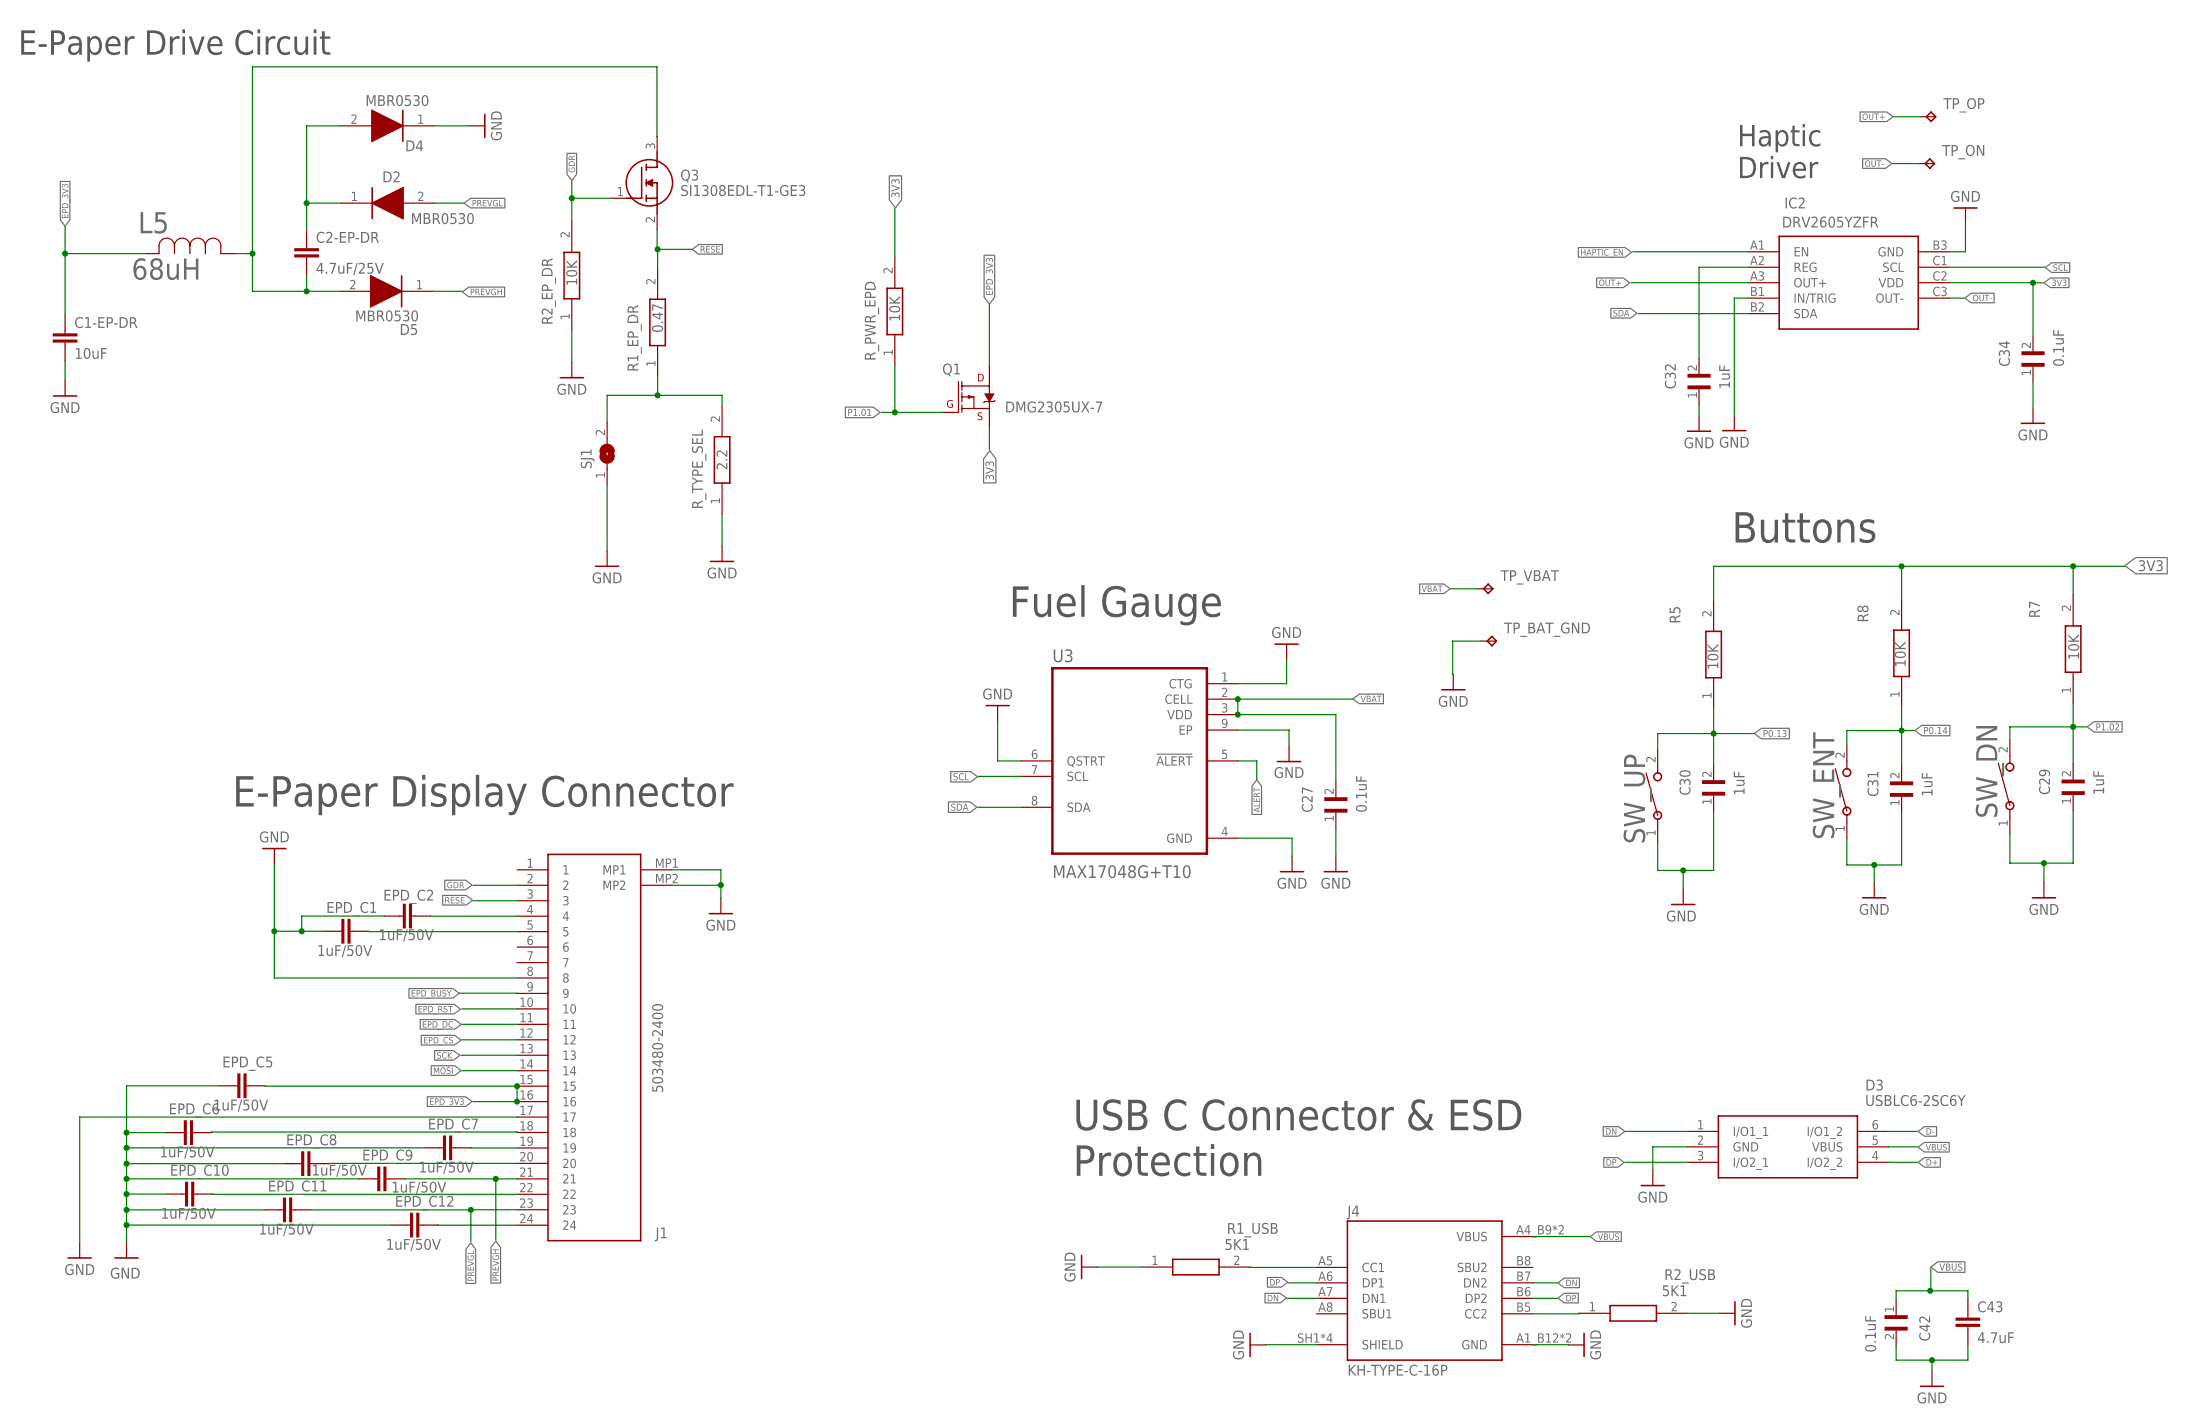
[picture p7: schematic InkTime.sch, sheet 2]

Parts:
C1-EP-DR: 10uF; NORDIC_NRF_3_RESC0402_N
C2-EP-DR: 4.7uF/25V; NORDIC_NRF_3_RESC0402_N
C27, C34, C42: 0.1uF; GRM011R60J152KE01L_2_CAPC0201X13N
C29, C30, C31, C32: 1uF; GRM011R60J152KE01L_2_CAPC0201X13N
C43: 4.7uF; NORDIC_NRF_3_RESC0402_N
D2, D4, D5: MBR0530; ESP32_C6_LIBRARY_5_SOD3716X135N
D3: USBLC6-2SC6Y; ESP32_C6_LIBRARY_3_SOT95P280X145-6N
EPD_C1, EPD_C2, EPD_C5, EPD_C6, EPD_C7, EPD_C8, EPD_C9, EPD_C10, EPD_C11, EPD_C12: 1uF/50V; NORDIC_NRF_3_RESC0402_N
IC2: DRV2605YZFR; DRV2605YZFR_BGA9C50P3X3_144X144X62
J1: 503480-2400; 503480-2400_5034802400
J4: KH-TYPE-C-16P; KH-TYPE-C-16P_KINGHELM_KH-TYPE-C-16P
L5: 68uH; ESP32_C6_LIBRARY_2_IND_4828-WE-TPC_WRE
Q1: DMG2305UX-7; ESP32_C6_LIBRARY_4_ESP32_C6_LIBRARY_4_ESP32_C6_LIBRARY_4_ES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
Q3: SI1308EDL-T1-GE3; ESP32_C6_LIBRARY_6_SOT65P210X110-3N
R1_EP_DR: 0.47; CPF0201D7K68C1_0201
R1_USB, R2_USB: 5K1; CPF0201D7K68C1_0201
R2_EP_DR, R5, R7, R8: 10K; CPF0201D7K68C1_0201
R_PWR_EPD: 10K; CPF0201D7K68C1_0201
R_TYPE_SEL: 2.2; CPF0201D7K68C1_0201
SJ1: ESP32_C6_LIBRARY_7_JUMPER_SJ
SW_DN: 2025-10-22_07-23-44_LIBRARY_EVP-AKE31A; 2025-10-22_07-23-44_LIBRARY_SW_EVP-AKE31A_PAN
SW_ENT: 2025-10-22_07-23-44_LIBRARY_EVP-AKE31A; 2025-10-22_07-23-44_LIBRARY_SW_EVP-AKE31A_PAN
SW_UP: 2025-10-22_07-23-44_LIBRARY_EVP-AKE31A; 2025-10-22_07-23-44_LIBRARY_SW_EVP-AKE31A_PAN
TP_BAT_GND: HECTOR_WATCH_1_TPTP20R; HECTOR_WATCH_1_TP20R
TP_ON: HECTOR_WATCH_1_TPTP20R; HECTOR_WATCH_1_TP20R
TP_OP: HECTOR_WATCH_1_TPTP20R; HECTOR_WATCH_1_TP20R
TP_VBAT: HECTOR_WATCH_1_TPTP20R; HECTOR_WATCH_1_TP20R
U3: MAX17048G+T10; ESP32_C6_LIBRARY_SON50P200X200X80-9N

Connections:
3V3: C34.2, IC2.C2 (VDD), Q1.2 (S), R5.2, R7.2, R8.2, R_PWR_EPD.2; also elsewhere on the board
ALERT: U3.5 (!ALERT); also elsewhere on the board
D+: D3.4 (I/O2_2); also elsewhere on the board
D-: D3.6 (I/O1_2); also elsewhere on the board
DN: D3.1 (I/O1_1), J4.A7 (DN1), J4.B7 (DN2)
DP: D3.3 (I/O2_1), J4.A6 (DP1), J4.B6 (DP2)
EPD_3V3: C1-EP-DR.1, EPD_C5.2, J1.15, J1.16, L5.2, Q1.3 (D)
EPD_BUSY: J1.9; also elsewhere on the board
EPD_CS: J1.12; also elsewhere on the board
EPD_DC: J1.11; also elsewhere on the board
EPD_RST: J1.10; also elsewhere on the board
GDR: J1.2, Q3.1 (G), R2_EP_DR.2
GND: C1-EP-DR.2, C27.1, C29.1, C30.1, C31.1, C32.1, C34.1, C42.2, C43.2, D3.2 (GND), D4.1 (K), EPD_C1.1, EPD_C2.1, EPD_C5.1, EPD_C6.1, EPD_C7.1, EPD_C8.1, EPD_C9.1, EPD_C10.1, EPD_C11.1, EPD_C12.1, IC2.B1 (IN/TRIG), IC2.B3 (GND), J1.8, J1.17, J1.MP1, J1.MP2, J4.A1_B12 (GND), J4.A12_B1 (GND), J4.SH1 (SHIELD), J4.SH2 (SHIELD), J4.SH3 (SHIELD), J4.SH4 (SHIELD), R1_USB.1, R2_EP_DR.1, R2_USB.2, R_TYPE_SEL.1, SJ1.1, SW_DN.1, SW_ENT.1, SW_UP.1, TP_BAT_GND.TP, U3.1 (CTG), U3.4 (GND), U3.6 (QSTRT), U3.9 (EP); also elsewhere on the board
HAPTIC_EN: IC2.A1 (EN); also elsewhere on the board
MOSI: J1.14; also elsewhere on the board
unnamed: C32.2, IC2.A2 (REG)
unnamed: J4.A5 (CC1), R1_USB.2
unnamed: J4.B5 (CC2), R2_USB.1
unnamed: C2-EP-DR.2, D5.2 (A), L5.1, Q3.3 (D)
unnamed: C2-EP-DR.1, D2.1 (K), D4.2 (A)
unnamed: R1_EP_DR.1, R_TYPE_SEL.2, SJ1.2
unnamed: EPD_C2.2, J1.4
unnamed: EPD_C1.2, J1.5
unnamed: EPD_C6.2, J1.18
unnamed: EPD_C7.2, J1.19
unnamed: EPD_C8.2, J1.20
unnamed: EPD_C10.2, J1.22
unnamed: EPD_C12.2, J1.24
OUT+: IC2.A3 (OUT+), TP_OP.TP
OUT-: IC2.C3 (OUT-), TP_ON.TP
P0.13: C30.2, R5.1, SW_UP.2; also elsewhere on the board
P0.14: C31.2, R8.1, SW_ENT.2; also elsewhere on the board
P1.01: Q1.1 (G), R_PWR_EPD.1; also elsewhere on the board
P1.02: C29.2, R7.1, SW_DN.2; also elsewhere on the board
PREVGH: D5.1 (K), EPD_C9.2, J1.21
PREVGL: D2.2 (A), EPD_C11.2, J1.23
RESE: J1.3, Q3.2 (S), R1_EP_DR.2
SCK: J1.13; also elsewhere on the board
SCL: IC2.C1 (SCL), U3.7 (SCL); also elsewhere on the board
SDA: IC2.B2 (SDA), U3.8 (SDA); also elsewhere on the board
VBAT: C27.2, TP_VBAT.TP, U3.2 (CELL), U3.3 (VDD); also elsewhere on the board
VBUS: C42.1, C43.1, D3.5 (VBUS), J4.A4_B9 (VBUS), J4.A9_B4 (VBUS); also elsewhere on the board

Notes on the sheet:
Fuel Gauge
Haptic Driver
Buttons
USB C Connector & ESD Protection
E-Paper Drive Circuit
E-Paper Display Connector

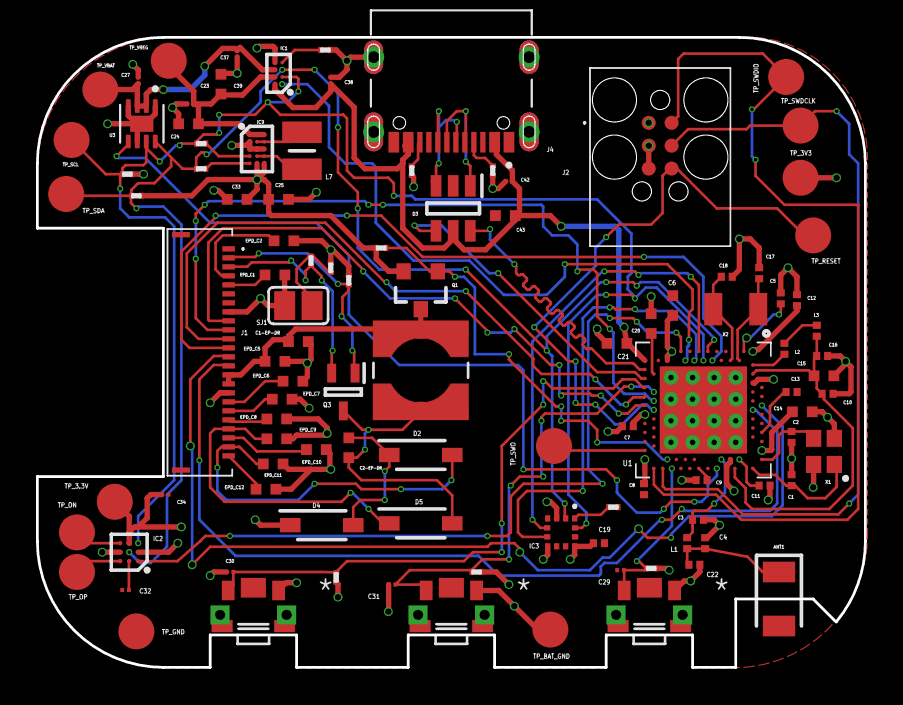
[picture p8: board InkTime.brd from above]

Board: 4 copper layers, 46.0 x 35.0 mm, 105 parts (0 on the bottom side), 70 nets.

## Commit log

2026-04-10 Add Hardware folder
    [InkTime.brd, InkTime.sch]
2026-04-17 Add PCB with silkscreen layer
    [InkTime.brd]
2026-04-20 Update README.md
    Removed estimated battery life information from README.
2026-04-20 Fixed minor schematic and board issues
    [InkTime.brd, InkTime.sch]
2026-04-21 Add printout of schematic
2026-04-21 Fix small overlap
    [InkTime.brd]

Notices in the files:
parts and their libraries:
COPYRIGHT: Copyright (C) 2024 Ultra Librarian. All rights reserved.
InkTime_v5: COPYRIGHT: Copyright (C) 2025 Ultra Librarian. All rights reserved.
